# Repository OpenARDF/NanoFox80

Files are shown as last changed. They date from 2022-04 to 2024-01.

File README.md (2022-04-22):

# NanoFox80
NanoFox80 is a (relatively) simple full-featured low-power 80m transmitter for use in foxoring competitions.

<b>KiCad</b>

The KiCad folder holds files for generating the schematic, BOM, and PCB files using KiCad. 

<b>Software</b>

The Software folder holds files for compiling executable code on Atmel Studio 7.

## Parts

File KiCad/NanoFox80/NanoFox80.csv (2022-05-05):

Ref | Value | QTY PER | Footprint | Description | Digi-Key Part No. | LCSC Part Number | Link | Manufacturer | Manufacturer PN
AE101 | Antenna_Shield | 1 | Connector_PinHeader_2.54mm:PinHeader_1x02_P2.54mm_Vertical
BT101 | 6-12V | 1 | Connector_PinSocket_2.54mm:PinSocket_1x02_P2.54mm_Vertical
C101 C102 C106 C111 C112 C113 C116 C117 C122 C123 | 470nF | 10 | Capacitor_SMD:C_0805_2012Metric_Pad1.18x1.45mm_HandSolder |  | CAP CER 0.47UF 100V X7S 0805 | 445-5203-1-ND |  |  | TDK Corporation | C2012X7S2A474K125AB
C103 C104 C118 C119 | 10uF | 4 | Capacitor_SMD:C_0805_2012Metric_Pad1.18x1.45mm_HandSolder |  | CAP CER 10UF 10V X7R 0805 | 1276-1764-1-ND |  |  | Samsung Electro-Mechanics | CL21B106KPQNNNE
C105 | 220pF | 1 | Capacitor_SMD:C_0805_2012Metric_Pad1.18x1.45mm_HandSolder |  | CAP CER 220PF 200V C0G/NP0 0805 | 478-1274-1-ND |  |  | KYOCERA AVX | 08052A221JAT2A
C107 C120 | 10nF | 2 | Capacitor_SMD:C_0805_2012Metric_Pad1.18x1.45mm_HandSolder |  | CAP CER 10000PF 50V X7R 0805 | 1276-1015-1-ND |  |  | Samsung Electro-Mechanics | CL21B103KBANNNC
C108 C109 C121 | 100nF | 3 | Capacitor_SMD:C_0805_2012Metric_Pad1.18x1.45mm_HandSolder |  | CAP CER 0.1UF 25V X7R 0805 | 1276-1099-1-ND |  |  | Samsung Electro-Mechanics | CL21B104KACNNNC
C110 | 1uF | 1 | Capacitor_SMD:C_0805_2012Metric_Pad1.18x1.45mm_HandSolder |  | CAP CER 1UF 25V X7R 0805 | 1276-1066-1-ND |  |  | Samsung Electro-Mechanics | CL21B105KAFNNNE
C114 | 67pF | 1 | Capacitor_SMD:C_0805_2012Metric_Pad1.18x1.45mm_HandSolder |  | CAP CER 68PF 50V C0G/NP0 0805 | 478-1314-1-ND |  |  | KYOCERA AVX | 08055A680JAT2A
C115 | 560nF | 1 | Capacitor_SMD:C_0805_2012Metric_Pad1.18x1.45mm_HandSolder |  | CAP CER 0.56UF 50V X7R 0805 | 399-C0805C564K5RAC7800CT-ND |  |  | KEMET | C0805C564K5RAC7800
D101 | LED_Filled | 1 | LED_SMD:LED_APDA1806SECK |  | LED RED CLEAR SMD RIGHT ANGLE | 754-2329-1-ND |  |  | Kingbright | APDA1806SECK/J3-PRV
D102 | SMV1253-079LF | 1 | Diode_SMD:D_SC-80 |  | DIODE VAR HYPRABRUPT JUNC TUNING | 863-SMV1253-079LFCT-ND |  |  | Skyworks Solutions Inc. | SMV1253-079LF
FB101 | FerriteBead_Small | 1 | Inductor_SMD:Ferrite_Bead_NFZ32BW881_Reflow |  | FERRITE BEAD 880 OHM 2SMD 1LN | 490-9310-1-ND |  |  | Murata Electronics | NFZ32BW881HN10L
J101 J104 J105 J106 J107 J109 J112 J113 J114 J115 | Conn_01x02 | 10 | Connector_PinSocket_2.54mm:PinSocket_1x02_P2.54mm_Vertical
J102 | Conn_01x02 | 1 | Connector_PinSocket_2.54mm:PinSocket_1x02_P2.54mm_Vertical |  |  | np |  | np | np
J103 J108 | Conn_01x01 | 2 | Connector_PinSocket_2.54mm:PinSocket_1x01_P2.54mm_Vertical
J110 | I2C | 1 | Connector_PinHeader_2.54mm:PinHeader_1x02_P2.54_Nonpolarized
J111 | DB9 Female | 1 | Connector_Dsub:DSUB-9_Female_EdgeMount_P2.77mm |  |  | 609-1525-ND |  | <a href="https://www.digikey.com/products/en?keywords=609-1525-ND">Link</a> | TH | TH
JP101 JP102 JP103 JP104 JP105 | SolderJumper_3_Bridged12 | 5 | Jumper:SolderJumper-3_P1.3mm_Bridged12_RoundedPad1.0x1.5mm_NumberLabels
JP106 | SolderJumper_2_Bridged | 1 | Jumper:SolderJumper-2_P1.3mm_Bridged_RoundedPad1.0x1.5mm
L101 | 8uH | 1 | Transformer_THT:Autotransformer_Toroid_1Tap_Horizontal_D14.0mm_Amidon-T50 |  | FT-50-67 or FT-82-67 | FT-50-67 (Amidon) |  | <a href="http://www.amidoncorp.com/ft-50A-43/">Link</a> | TH | TH
P101 | ISP/PDI | 1 | Connector_PinHeader_2.54mm:PinHeader_2x03_P2.54mm_Vertical_SMD |  |  | 609-3487-1-ND |  | <a href="https://www.digikey.com/products/en?keywords=609-3487-1-ND">Link</a> | Amphenol ICC (FCI) | 95278-101A06LF
Q101 | BSS84W-7-F | 1 | Package_TO_SOT_SMD:SOT-323_SC-70 |  | MOSFET P-CH 50V 130MA SOT323 | BSS84W-FDICT-ND |  |  | Diodes Incorporated | BSS84W-7-F
Q102 | BSS138W-7-F | 1 | Package_TO_SOT_SMD:SOT-323_SC-70 |  | MOSFET N-CH 50V 200MA SOT323 | BSS138W-FDICT-ND |  |  | Diodes Incorporated | BSS138W-7-F
R101 R102 | 200k | 2 | Resistor_SMD:R_0805_2012Metric_Pad1.20x1.40mm_HandSolder |  | RES SMD 200K OHM 1% 1/8W 0805 | RHM200KAHCT-ND |  |  | Rohm Semiconductor | KTR10EZPF2003
R103 R107 | np | 2 | Resistor_SMD:R_0805_2012Metric_Pad1.20x1.40mm_HandSolder
R104 R109 R112 | 100k | 3 | Resistor_SMD:R_0805_2012Metric_Pad1.20x1.40mm_HandSolder |  | RES 100K OHM 0.1% 1/8W 0805 | 2019-RN73H2ATTD1003B25CT-ND |  |  | KOA Speer Electronics Inc. | RN73H2ATTD1003B25
R105 | 22k | 1 | Resistor_SMD:R_0805_2012Metric_Pad1.20x1.40mm_HandSolder |  | RES SMD 22K OHM 1% 1/8W 0805 | A106059CT-ND |  |  | TE Connectivity Passive Product | CRG0805F22K
R106 | 15.8k | 1 | Resistor_SMD:R_0805_2012Metric_Pad1.20x1.40mm_HandSolder |  | RES 15.8K OHM 1% 1/8W 0805 | RMCF0805FT15K8CT-ND |  |  | Stackpole Electronics Inc | RMCF0805FT15K8
R108 | 1k | 1 | Resistor_SMD:R_0805_2012Metric_Pad1.20x1.40mm_HandSolder |  | RES 1K OHM 1% 1/4W 0805 | RNCP0805FTD1K00CT-ND |  |  | Stackpole Electronics Inc | RNCP0805FTD1K00
R110 | 162k | 1 | Resistor_SMD:R_0805_2012Metric_Pad1.20x1.40mm_HandSolder |  | RES 162K OHM 1% 1/8W 0805 | 311-162KCRCT-ND |  |  | YAGEO | RC0805FR-07162KL
R111 | 12.4k | 1 | Resistor_SMD:R_0805_2012Metric_Pad1.20x1.40mm_HandSolder |  | RES 12.4K OHM 1% 1/8W 0805 | RMCF0805FT12K4CT-ND |  |  | Stackpole Electronics Inc | RMCF0805FT12K4
SW101 | SW_SPST | 1 | Button_Switch_SMD:SW_SPST_B3U-3000P-B |  | SWITCH TACTILE SPST-NO 0.05A 12V | SW1256CT-ND |  |  | Omron Electronics Inc-EMC Div | B3U-3000P-B
U101 | UCC27517DBVR | 1 | Package_TO_SOT_SMD:SOT-23-5 |  | IC GATE DRVR LOW-SIDE SOT23-5 | 296-39527-1-ND |  |  | Texas Instruments | UCC27517DBVR
U102 | LP2985-3.3 | 1 | Package_TO_SOT_SMD:SOT-23-5 |  | IC REG LINEAR 3.3V 150MA SOT23-5 | 296-18479-1-ND |  |  | Texas Instruments | LP2985A-33DBVR
U103 | LMV721M5 | 1 | Package_TO_SOT_SMD:SOT-23-5 |  | IC OPAMP GP 1 CIRCUIT SOT23-5 | LMV721M5/NOPBCT-ND |  | https://www.digikey.com/en/products/detail/texas-instruments/LMV721M5-NOPB/364402 | Texas Instruments | LMV721M5/NOPB
U104 | 74HC4046 | 1 | Package_SO:SOIC-16W_5.3x10.2mm_P1.27mm |  | IC PLL CMOS LOGIC W/VCO HS 16SO | SN74LV4046ANS-ND | C1535861 | https://www.digikey.com/products/en?keywords=SN74LV4046ANS-ND | Texas Instruments | SN74LV4046ANS
U105 | AVR128DA28 | 1 | Package_SO:SOIC-28W_7.5x17.9mm_P1.27mm |  | IC MCU 8BIT 128KB FLASH 28SOIC | 150-AVR128DA28T-E/SOCT-ND |  |  | Microchip Technology | AVR128DA28T-E/SO
U106 U107 | 74HC390 | 2 | Package_SO:SOIC-16W_5.3x10.2mm_P1.27mm |  | IC DUAL DECADE RIP CNTR 16SOIC | 296-33078-5-ND |  |  | Texas Instruments | CD74HC390M
U108 | LP2985-5.0 | 1 | Package_TO_SOT_SMD:SOT-23-5 |  | IC REG LINEAR 5V 150MA SOT23-5 | 296-20717-1-ND |  |  | Texas Instruments | LP2985-50DBVR
U109 | TXB0102DCU | 1 | Package_SO:VSSOP-8_2.4x2.1mm_P0.5mm |  | IC TRNSLTR BIDIRECTIONAL US8 | 296-32601-1-ND |  |  | Texas Instruments | TXB0102DCUT
W101 | TP2 | 1 | Measurement:Measurement_Point_ScopeProbe_Round-SMD-2sides-Pad_Small
W102 | TP3 | 1 | Measurement:Measurement_Point_ScopeProbe_Round-SMD-2sides-Pad_Small
W103 | TP1 | 1 | Measurement:Measurement_Point_ScopeProbe_Round-SMD-2sides-Pad_Small
X101 | SIT1566AC TCO | 1 | Oscillator:Oscillator_SMD_SiTime_SIT1566AC-4Pin_BGA |  | MEMS OSC TCXO 32.768KHZ CSP | 1473-SIT1566AC-JV-XXE-32.768ECT-ND |  |  | SiTime | SIT1566AC-JV-XXE-32.768E

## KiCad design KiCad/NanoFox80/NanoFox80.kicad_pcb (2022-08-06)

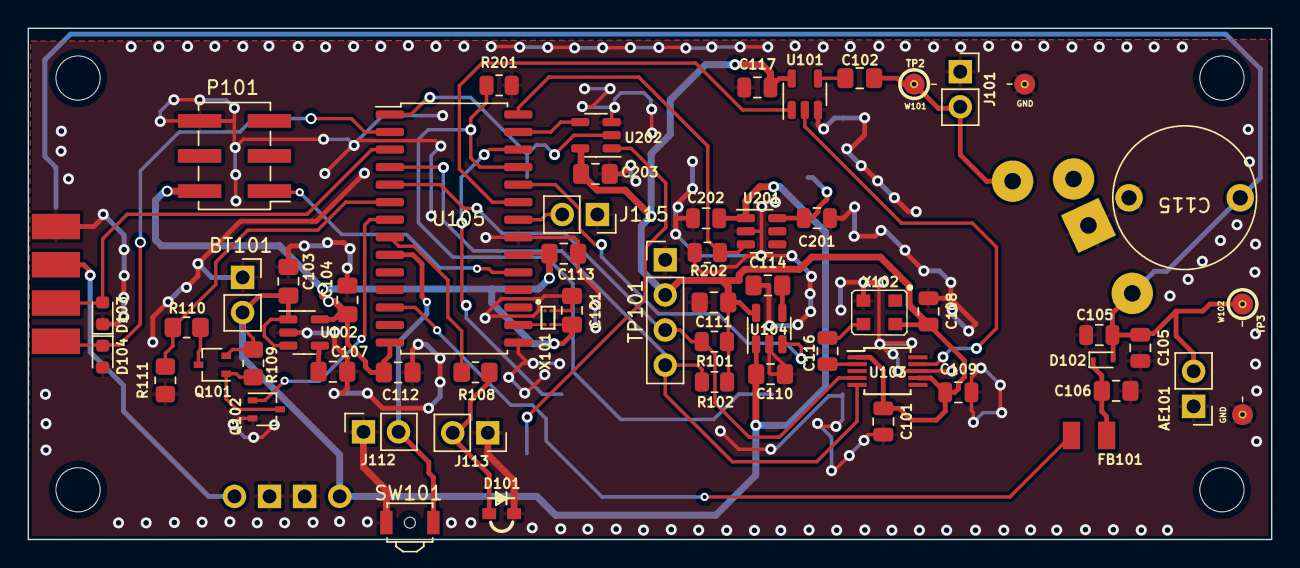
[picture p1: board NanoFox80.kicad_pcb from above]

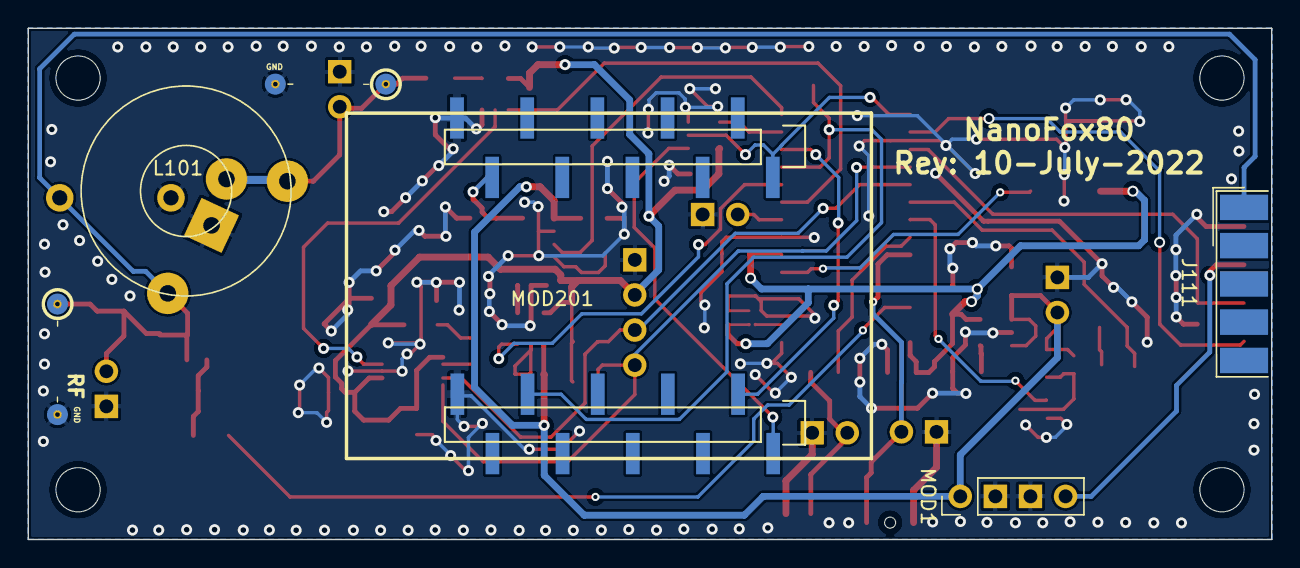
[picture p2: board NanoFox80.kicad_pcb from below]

Board: 2 copper layers, 90.0 x 37.0 mm, 61 parts (4 on the bottom side), 38 nets.

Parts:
AE101: Antenna_Shield; PinHeader_1x02_P2.54mm_Vertical
BT101: 3.5-9V; PinSocket_1x02_P2.54mm_Vertical
C101, C109: 470nF; C_0805_2012Metric
C102, C121, C203: 100nF; C_0805_2012Metric_Pad1.18x1.45mm_HandSolder
C103, C104, C110, C111: 10uF; C_0805_2012Metric_Pad1.18x1.45mm_HandSolder
C105, C105#2: 220pF; C_0805_2012Metric
C106, C112, C113: 470nF; C_0805_2012Metric_Pad1.18x1.45mm_HandSolder
C107, C114: 10nF; C_0805_2012Metric_Pad1.18x1.45mm_HandSolder
C108, C116, C117: 100nF; C_0805_2012Metric
C115: 15-60pF; CP_Radial_Ceramic_Trimmer_D9.4mm_P8.00mm
C201: 10uF; C_0805_2012Metric
C202: 4.7uF; C_0805_2012Metric
D101: LED_Filled; LED_APDA1806SECK
D102: SMV1253-079LF; D_SC-80
D103, D104: ESD9B5.0ST5G_1; D_0603_1608Metric
FB101: FerriteBead_Small; Ferrite_Bead_NFZ32BW881_Reflow
J101, J112, J113, J115: Conn_01x02; PinSocket_1x02_P2.54mm_Vertical
J111: DB9 Female; DSUB-9_Female_EdgeMount_P2.77mm
L101: 8uH; Autotransformer_Toroid_1Tap_Horizontal_D14.0mm_Amidon-T50
MOD1: AdaFruit Charger; PinHeader_1x04_P2.54mm_Vertical
MOD201: HUZZAH_ESP8266_Breakout; Adafruit_HUZZAH_ESP8266_Breakout_SM
P101: ISP/PDI; PinHeader_2x03_P2.54mm_Vertical_SMD
Q101: BSS84W-7-F; SOT-323_SC-70
Q102: BSS138W-7-F; SOT-323_SC-70
R101, R102, R202: 10k; R_0805_2012Metric
R108: 1k; R_0805_2012Metric_Pad1.20x1.40mm_HandSolder
R109: 100k; R_0805_2012Metric_Pad1.20x1.40mm_HandSolder
R110: 162k; R_0805_2012Metric_Pad1.20x1.40mm_HandSolder
R111: 12.4k; R_0805_2012Metric_Pad1.20x1.40mm_HandSolder
R201: 560k; R_0805_2012Metric
SW101: SW_SPST; SW_SPST_B3U-3000P-B
TP101: I2C1; PinHeader_1x04_P2.54mm_Vertical
U101: MC74VHC1G125; TSOT-23-5
U102, U104: LP2985-3.3; SOT-23-5
U103: SI5351; MSOP-10_3x3mm_P0.5mm
U105: AVR128DA28; SOIC-28W_7.5x17.9mm_P1.27mm
U201: TPS22810DBVT; SOT-23-6
U202: 74HC1G08; SOT-23-5
W101: TP2; Measurement_Point_ScopeProbe_Round-SMD-2sides-Pad_Small
W102: TP3; Measurement_Point_ScopeProbe_Round-SMD-2sides-Pad_Small
X101: SIT1566AC TCO; Oscillator_SMD_SiTime_SIT1566AC-4Pin_BGA
X102: 25 MHz; Crystal_SMD_TXETCLSANF-4Pin

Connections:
+3V3: C104.2, C112.1, C113.2, C121.2, P101.2, U102.5 (VOUT), U105.14 (AVDD), U105.20 (VDD), X101.3 (Vdd)
+BATT: BT101.2 (+), C103.2, C110.2, C202.2, MOD1.1, Q101.2 (S), R109.1, U102.1 (VIN), U102.3 (ON/~OFF), U104.1 (VIN), U201.1 (VIN)
Antenna: AE101.2 (A), C105.1, C105#2.1, C115.1, D102.2 (A), J111.1, L101.1, W102.1
Enable_RF: U104.3 (ON/~OFF), U105.24 (PA2)
Enable_Vdiv: Q102.1 (G), U105.7 (PD1)
GND: AE101.1 (Shield), BT101.1 (-), C101.2, C103.1, C104.1, C105.2, C105#2.2, C106.1, C107.2, C108.2, C109.2, C110.1, C111.1, C112.2, C113.1, C114.2, C115.2, C117.1, C121.1, C201.1, C202.1, C203.1, D101.1 (K), D103.1 (A1), D104.2 (A2), J101.1, J111.6, J112.1, J113.1, J115.1, L101.3, MOD1.2, MOD1.3, MOD201.10 (GND), MOD201.11 (GND), P101.6, Q102.2 (S), R111.1, R201.2, R202.1, SW101.2 (B), TP101.1, U101.3 (GND), U102.2 (GND), U103.8 (GND), U104.2 (GND), U105.15 (GND), U105.21 (GND), U201.2 (GND), U202.3 (GND), W101.2, W102.2, X101.4 (GND), X102.2 (GND)
unnamed: C102.1, J101.2, L101.2 (TAP), W101.1
unnamed: C102.2, U101.4 (Y)
unnamed: C106.2, D102.1 (K), FB101.1
unnamed: C107.1, U102.4 (BP)
unnamed: C114.1, U104.4 (BP)
unnamed: C116.1, U103.2 (XA)
unnamed: C116.2, X102.3 (OUT)
unnamed: C201.2, MOD201.9 (VBat), U201.6 (VOUT)
unnamed: D101.2 (A), J113.2, R108.2
unnamed: D103.2 (A2), J111.8, U105.3 (PC1/RxD1)
unnamed: D104.1 (A1), J111.9, U105.2 (PC0/TxD1)
unnamed: FB101.2, U105.12 (PD6/DAC)
unnamed: J112.2, SW101.1 (A), U105.9 (PD3)
unnamed: J115.2, U105.22 (PA0/EXTCLK)
unnamed: MOD201.20 (TX), U202.1
unnamed: P101.1, U105.19 (UDPI)
unnamed: Q101.1 (G), Q102.3 (D), R109.2
unnamed: Q101.3 (D), R110.2
unnamed: R101.2, TP101.3, U103.4 (SCL), U105.5 (PC3/SCL)
unnamed: R102.2, TP101.4, U103.5 (SDA), U105.4 (PC2/SDA)
unnamed: R108.1, U105.8 (PD2)
unnamed: U101.1 (~OE), U105.23 (PA1)
unnamed: U101.2 (A), U103.9 (CLK1)
unnamed: U105.16 (PF0/XTAL32k1), X101.2 (OUT)
V+_Charging: J111.7, MOD1.4
VCC: C101.1, C108.1, C109.1, C111.2, C117.2, C203.2, R101.1, R102.1, TP101.2, U101.5 (VCC), U103.1 (VDD), U103.7 (VDDO), U104.5 (VOUT), U202.5 (VCC), X102.4 (Vcc)
Vbat: R110.1, R111.2, U105.6 (PD0/AIN0)
WIFI_ENABLE: R202.2, U105.28 (PA6), U201.3 (EN/UVLO)
WIFI_RX: MOD201.19 (RX), U105.26 (PA4)
WIFI_TX: U105.27 (PA5), U202.4
WiFi Module Detect: MOD201.13 (3V), R201.1, U105.25 (PA3)
~WIFI_RESET: MOD201.1 (~RST), U105.1 (PA7), U202.2

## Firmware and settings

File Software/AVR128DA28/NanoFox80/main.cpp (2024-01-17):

#include "atmel_start.h"
#include <avr/io.h>
#include <avr/interrupt.h>
#include <string.h>
#include <time.h>
#include <stdio.h>
#include <ctype.h>
#include <avr/sleep.h>
#include <atomic.h>

#include "serialbus.h"
#include "transmitter.h"
#include "morse.h"
#include "adc.h"
#include "util.h"
#include "binio.h"
#include "eeprommanager.h"
#include "binio.h"
#include "leds.h"
#include "CircularStringBuff.h"
#include "rtc.h"
#include "rstctrl.h"

#include <cpuint.h>
#include <ccp.h>
#include <atomic.h>


/***********************************************************************
 * Local Typedefs
 ************************************************************************/

typedef enum
{
	WD_SW_RESETS,
	WD_HW_RESETS,
	WD_FORCE_RESET,
	WD_DISABLE
} WDReset;

typedef enum
{
	AWAKENED_INIT,
	POWER_UP_START,
	AWAKENED_BY_CLOCK,
	AWAKENED_BY_BUTTONPRESS
} Awakened_t;

typedef enum
{
	HARDWARE_OK,
	HARDWARE_NO_RTC = 0x01,
	HARDWARE_NO_SI5351 = 0x02
//	,HARDWARE_NO_WIFI = 0x04
} HardwareError_t;


typedef enum {
	SYNC_Searching_for_slave,
	SYNC_Align_to_Second_Transition,
	SYNC_Waiting_for_CLK_T_reply,
	SYNC_Waiting_for_CLK_S_reply,
	SYNC_Waiting_for_CLK_F_reply,
	SYNC_Waiting_for_CLK_D_reply,
	SYNC_Waiting_for_ID_reply,
	SYNC_Waiting_for_ID_CodeSpeed_reply,
	SYNC_Waiting_for_Pattern_CodeSpeed_reply,
	SYNC_Waiting_for_EVT_reply,
	SYNC_Waiting_for_NoEvent_Freq_reply,
	SYNC_Waiting_for_Freq_Low_reply,
	SYNC_Waiting_for_Freq_Med_reply,
	SYNC_Waiting_for_Freq_Hi_reply,
	SYNC_Waiting_for_Freq_Beacon_reply,
// 	SYNC_Waiting_for_PAT_A_reply,
// 	SYNC_Waiting_for_PAT_B_reply,
// 	SYNC_Waiting_for_PAT_C_reply,
// 	SYNC_Waiting_for_FRE_A_reply,
// 	SYNC_Waiting_for_FRE_B_reply,
// 	SYNC_Waiting_for_FRE_C_reply,
	SYNC_Waiting_for_ACK
} SyncState_t;

#define PROGRAMMING_MESSAGE_TIMEOUT_PERIOD 9000


/***********************************************************************
 * Global Variables & String Constants
 *
 * Identify each global with a "g_" prefix
 * Whenever possible limit globals' scope to this file using "static"
 * Use "volatile" for globals shared between ISRs and foreground
 ************************************************************************/
#define TEMP_STRING_SIZE 50
static char g_tempStr[TEMP_STRING_SIZE+1] = { '\0' };
static volatile EC g_last_error_code = ERROR_CODE_NO_ERROR;
static volatile SC g_last_status_code = STATUS_CODE_IDLE;

static volatile bool g_powering_off = false;

static volatile uint16_t g_util_tick_countdown = 0;
static volatile bool g_battery_measurements_active = false;
static volatile uint16_t g_maximum_battery = 0;

static volatile bool g_start_event = false;

static volatile int32_t g_on_the_air = 0;
static volatile int g_sendID_seconds_countdown = 0;
static volatile uint16_t g_code_throttle = 50;
static volatile uint16_t g_sleepshutdown_seconds = 120;
static volatile bool g_report_seconds = false;
static volatile int g_hardware_error = (int)HARDWARE_OK;

char g_messages_text[STATION_ID+1][MAX_PATTERN_TEXT_LENGTH + 2];
volatile uint8_t g_id_codespeed = EEPROM_ID_CODE_SPEED_DEFAULT;
volatile uint8_t g_pattern_codespeed = EEPROM_PATTERN_CODE_SPEED_DEFAULT;
volatile uint8_t g_foxoring_pattern_codespeed = EEPROM_FOXORING_PATTERN_CODESPEED_DEFAULT;
volatile uint16_t g_time_needed_for_ID = 0;
volatile int16_t g_on_air_seconds = EEPROM_ON_AIR_TIME_DEFAULT;                      /* amount of time to spend on the air */
volatile int16_t g_off_air_seconds = EEPROM_OFF_AIR_TIME_DEFAULT;                    /* amount of time to wait before returning to the air */
volatile int16_t g_intra_cycle_delay_time = EEPROM_INTRA_CYCLE_DELAY_TIME_DEFAULT;   /* offset time into a repeating transmit cycle */
volatile int16_t g_ID_period_seconds = EEPROM_ID_TIME_INTERVAL_DEFAULT;              /* amount of time between ID/callsign transmissions */
volatile time_t g_event_start_epoch = EEPROM_START_TIME_DEFAULT;
volatile time_t g_event_finish_epoch = EEPROM_FINISH_TIME_DEFAULT;
volatile bool g_event_enabled = EEPROM_EVENT_ENABLED_DEFAULT;                        /* indicates that the conditions for executing the event are set */
volatile bool g_event_commenced = false;
volatile float g_voltage_threshold = EEPROM_BATTERY_THRESHOLD_V;
volatile float g_battery_voltage = 0.;
volatile bool g_seconds_transition = false;
volatile bool g_sending_station_ID = false;											/* Allows a small extension of transmissions to ensure the ID is fully sent */
volatile bool g_muteAfterID = false;												/* Inhibit any transmissions after the ID has been sent */
volatile uint32_t g_event_checksum = 0;
volatile uint8_t g_days_to_run = 1;
volatile uint8_t g_days_run = 0;
extern uint16_t g_clock_calibration;

static volatile bool g_run_event_forever = false;
static volatile bool g_go_to_sleep_now = false;
static volatile bool g_sleeping = false;
static volatile time_t g_time_to_wake_up = 0;
static volatile Awakened_t g_awakenedBy = POWER_UP_START;
static volatile SleepType g_sleepType = SLEEP_FOREVER;

#define NUMBER_OF_POLLED_ADC_CHANNELS 1
static ADC_Active_Channel_t g_adcChannelOrder[NUMBER_OF_POLLED_ADC_CHANNELS] = { ADCExternalBatteryVoltage };
enum ADC_Result_Order { EXTERNAL_BATTERY_VOLTAGE };
static const uint16_t g_adcChannelConversionPeriod_ticks[NUMBER_OF_POLLED_ADC_CHANNELS] = { TIMER2_0_5HZ };
static volatile uint16_t g_adcCountdownCount[NUMBER_OF_POLLED_ADC_CHANNELS] = { 2000 };
//static uint16_t g_ADCFilterThreshold[NUMBER_OF_POLLED_ADC_CHANNELS] = { 500, 500, 500 };
static volatile bool g_adcUpdated[NUMBER_OF_POLLED_ADC_CHANNELS] = { false };
static volatile uint16_t g_lastConversionResult[NUMBER_OF_POLLED_ADC_CHANNELS];

volatile uint16_t g_switch_closed_time = 0;
volatile uint16_t g_handle_counted_presses = 0;
volatile uint16_t g_switch_presses_count = 0;
volatile bool g_long_button_press = false;

static volatile uint16_t g_programming_countdown = 0;
static volatile uint16_t g_programming_msg_throttle = 0;
static volatile uint16_t g_send_clone_success_countdown = 0;
static SyncState_t g_programming_state = SYNC_Searching_for_slave;
bool g_cloningInProgress = false;
Enunciation_t g_enunciator = LED_ONLY;

uint16_t g_Event_Configuration_Check = 0;

leds LEDS = leds();
CircularStringBuff g_text_buff = CircularStringBuff(TEXT_BUFF_SIZE);

EepromManager g_ee_mgr;

bool g_isMaster = false;
uint16_t isMasterCountdownSeconds = 0;
Fox_t g_fox[] = {FOX_1, FOX_1, SPRINT_S1, FOXORING_FOX1, INVALID_FOX}; /* none, classic, sprint, foxoring, blind */

Event_t g_event = EEPROM_EVENT_SETTING_DEFAULT;
Frequency_Hz g_frequency = EEPROM_FREQUENCY_DEFAULT;
Frequency_Hz g_frequency_low = EEPROM_FREQUENCY_LOW_DEFAULT;
Frequency_Hz g_frequency_med = EEPROM_FREQUENCY_MED_DEFAULT;
Frequency_Hz g_frequency_hi = EEPROM_FREQUENCY_HI_DEFAULT;
Frequency_Hz g_frequency_beacon = EEPROM_FREQUENCY_BEACON_DEFAULT;

int8_t g_utc_offset;
uint8_t g_unlockCode[UNLOCK_CODE_SIZE + 2];

extern volatile uint16_t g_i2c_failure_count;

volatile bool g_enable_manual_transmissions = true;

/***********************************************************************
 * Private Function Prototypes
 *
 * These functions are available only within this file
 ************************************************************************/
void handle_1sec_tasks(void);
bool eventEnabled(void);
void handleSerialBusMsgs(void);
void wdt_init(WDReset resetType);
uint16_t throttleValue(uint8_t speed);
EC activateEventUsingCurrentSettings(SC* statusCode);
EC launchEvent(SC* statusCode);
EC hw_init(void);
EC rtc_init(void);
bool antennaIsConnected(void);
void powerDown3V3(void);
void powerUp3V3(void);
char* convertEpochToTimeString(time_t epoch, char* buf, size_t size);
time_t String2Epoch(bool *error, char *datetime);
void reportSettings(void);
uint16_t timeNeededForID(void);
Frequency_Hz getFrequencySetting(void);
char* getCurrentPatternText(void);
int getPatternCodeSpeed(void);
int getFoxCodeSpeed(void);
Fox_t getFoxSetting(void);
void handleSerialCloning(void);
bool eventScheduled(void);
bool eventScheduledForNow(void);
bool eventScheduledForTheFuture(void);
bool noEventWillRun(void);
time_t pauseUntilSecTransition(void);

/*******************************/
/* Hardcoded event support     */
/*******************************/
void initializeAllEventSettings(bool disableEvent);
void suspendEvent(void);
void stopEventNow(EventActionSource_t activationSource);
void startEventNow(EventActionSource_t activationSource);
bool startEventUsingRTC(void);
void setupForFox(Fox_t fox, EventAction_t action);
time_t validateTimeString(char* str, time_t* epochVar);
bool reportTimeTill(time_t from, time_t until, const char* prefix, const char* failMsg);
ConfigurationState_t clockConfigurationCheck(void);
void reportConfigErrors(void);
/*******************************/
/* End hardcoded event support */
/*******************************/

ISR(RTC_CNT_vect)
{
	uint8_t x = RTC.INTFLAGS;
	
    if (x & RTC_OVF_bm )
    {
        system_tick();

		if(g_on_the_air < 0)
		{
			g_on_the_air++;
		}
		else if(g_on_the_air > 0)
		{
			g_on_the_air--;
		}
		
		g_seconds_transition = true;

		if(g_sleeping)
		{
			if(g_sleepType != SLEEP_FOREVER)
			{
				if(g_sleepType == SLEEP_UNTIL_NEXT_XMSN)
				{
					if((g_on_the_air > -6) || (g_time_to_wake_up <= time(null))) /* Always wake up at least 5 seconds before showtime */
					{
						g_go_to_sleep_now = false;
						g_sleeping = false;
						g_awakenedBy = AWAKENED_BY_CLOCK;
					}
				}
				else
				{
					if(g_time_to_wake_up <= time(null))
					{
						g_go_to_sleep_now = false;
						g_sleeping = false;
						g_awakenedBy = AWAKENED_BY_CLOCK;
					}
				}
			}
		}
		else
		{
			handle_1sec_tasks();
		}
	}
 
    RTC.INTFLAGS = (RTC_OVF_bm | RTC_CMP_bm);
}


/**
1-Second Interrupts:
One-second counter based on RTC.
*/
void handle_1sec_tasks(void)
{
	time_t temp_time = 0;
	
	if(isMasterCountdownSeconds) isMasterCountdownSeconds--;

	if(!g_cloningInProgress)
	{
		temp_time = time(null);

		if(g_event_commenced && !g_run_event_forever)
		{
			if(g_event_finish_epoch) /* If a finish time has been set */
			{
				if(temp_time >= g_event_finish_epoch)
				{
					g_last_status_code = STATUS_CODE_EVENT_FINISHED;
					g_on_the_air = 0;
					keyTransmitter(OFF);
					g_event_enabled = false;
					g_event_commenced = false;
					g_sleepshutdown_seconds = 120;
					LEDS.init();
					g_days_run++;
				
					if(g_days_run < g_days_to_run)
					{
						g_event_start_epoch += SECONDS_24H;
						g_event_finish_epoch += SECONDS_24H;
						g_sleepType = SLEEP_UNTIL_START_TIME;
						g_go_to_sleep_now = true;
					}
					else
					{
						g_sleepType = SLEEP_FOREVER;
						g_sleepshutdown_seconds = 3;
					}
				}
			}
		}

		if(g_event_enabled && !g_isMaster)
		{
			if(g_event_commenced) /* an event is in progress */
			{
				if(g_sendID_seconds_countdown)
				{
					g_sendID_seconds_countdown--;
				}
				
 				if(g_fox[g_event] == FREQUENCY_TEST_BEACON)
 				{
					static uint8_t selection = 0;
 					bool change = temp_time % 2;
 					
					if(!change)
					{
						if(selection == 0)
						{
							init_transmitter(g_frequency_low);
							g_code_throttle = throttleValue(14);
							bool repeat = true;
							makeMorse((char*)"E<<", &repeat, NULL, CALLER_AUTOMATED_EVENT);
							selection = 1;
						}
						else if(selection == 1)
						{
							init_transmitter(g_frequency_med);
							g_code_throttle = throttleValue(14);
							bool repeat = true;
							makeMorse((char*)"I<<", &repeat, NULL, CALLER_AUTOMATED_EVENT);
							selection = 2;
						}
						else if(selection == 2)
						{
							init_transmitter(g_frequency_hi);
							g_code_throttle = throttleValue(14);
							bool repeat = true;
							makeMorse((char*)"S<<", &repeat, NULL, CALLER_AUTOMATED_EVENT);
							selection = 0;
						}
					}
 				}
			}
			else /* waiting for the start time to arrive */
			{
				if(g_event_start_epoch > MINIMUM_VALID_EPOCH) /* a start time has been set */
				{
					temp_time = time(null);

					if(temp_time >= g_event_start_epoch) /* Time for the event to start */
					{
						powerToTransmitter(ON);
				
						if(g_intra_cycle_delay_time)
						{
							g_last_status_code = STATUS_CODE_EVENT_STARTED_WAITING_FOR_TIME_SLOT;
							g_on_the_air = -g_intra_cycle_delay_time;
							g_sendID_seconds_countdown = g_intra_cycle_delay_time + g_on_air_seconds - g_time_needed_for_ID;
						}
						else
						{
							g_last_status_code = STATUS_CODE_EVENT_STARTED_NOW_TRANSMITTING;
							g_on_the_air = g_on_air_seconds;
							g_sendID_seconds_countdown = g_on_air_seconds - g_time_needed_for_ID;
						}
						
						g_code_throttle = throttleValue(getFoxCodeSpeed());
						bool repeat = true;
						makeMorse(getCurrentPatternText(), &repeat, NULL, CALLER_AUTOMATED_EVENT);
						
						g_event_commenced = true;
						LEDS.init();
					}
				}
			}
		}
	}

	/**************************************
	* Delay before sleep
	***************************************/
	if(g_sleepshutdown_seconds) g_sleepshutdown_seconds--;

	if(!g_sleepshutdown_seconds)
	{
 		if(g_isMaster || g_cloningInProgress)
 		{
	 		g_sleepshutdown_seconds = 120; /* Never sleep while cloning or while master */
 		}
		else if(g_event_commenced && g_event_enabled && ((g_sleepType != SLEEP_UNTIL_NEXT_XMSN) && (g_sleepType != SLEEP_UNTIL_START_TIME)))
		{
			g_sleepshutdown_seconds = 120; /* Never sleep during active transmissions */
		}
		else
		{
			if(g_sleepType == DO_NOT_SLEEP)
			{
				if(noEventWillRun()) /* Should never evaluate to true, but checking just in case */
				{
					g_sleepType = SLEEP_FOREVER;
				}
			}
			else if(!g_go_to_sleep_now)
			{
				if(g_sleepType == SLEEP_FOREVER)
				{
					if(eventScheduledForTheFuture()) /* Should never evaluate to true, but checking just in case */
					{
						g_sleepType = SLEEP_UNTIL_START_TIME;
					}
				}
				
				/* If we reach here, g_sleepType = 	SLEEP_UNTIL_START_TIME, SLEEP_UNTIL_NEXT_XMSN, SLEEP_USER_OVERRIDE, or SLEEP_FOREVER */
				g_go_to_sleep_now = true;
			}
		}
	}
}
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
int main(void)
{
	atmel_start_init();
	LEDS.blink(LEDS_OFF, true);
	powerUp3V3();
	
	g_ee_mgr.initializeEEPROMVars();
	g_ee_mgr.readNonVols();
	g_isMaster = false; /* Never start up as master */
	
	RTC_set_calibration(g_clock_calibration);
					
	/* Check that the RTC is running */
	set_system_time(YEAR_2000_EPOCH);
	time_t now = time(null);
	while((util_delay_ms(2000)) && (now == time(null)));
	
	sb_send_string(TEXT_RESET_OCCURRED_TXT);
	
	if(now == time(null))
	{
		g_hardware_error |= (int)HARDWARE_NO_RTC;
		RTC_init_backup();
	}
	
	if(init_transmitter(getFrequencySetting()) != ERROR_CODE_NO_ERROR)
	{
		if(!txIsInitialized())
		{
			g_hardware_error |= (int)HARDWARE_NO_SI5351;
		}
	}
	
	g_start_event = eventEnabled(); /* Start any event stored in EEPROM */
	
	reportSettings();
	sb_send_NewPrompt();

	g_sleepshutdown_seconds = 120;

	while (1) {
		if(g_handle_counted_presses)
		{
			if(g_handle_counted_presses == 1)
			{
				if(!g_isMaster && !g_cloningInProgress)
				{
					if(eventScheduled())
					{
						g_event_enabled = false;
						
						if(!g_run_event_forever)
						{
							setupForFox(INVALID_FOX, START_EVENT_NOW_AND_RUN_FOREVER); // Immediately start transmissions
						}
						else
						{
 							startEventUsingRTC();
						}
					}
					else
					{
						startEventNow(PROGRAMMATIC);						
					}
				}
			}
			else if (g_handle_counted_presses == 2)
			{
				suspendEvent();
				g_sleepType = SLEEP_USER_OVERRIDE;
			}
			else if(g_isMaster)
			{
				if((g_handle_counted_presses == 4) && txIsInitialized()) // keydown forever
				{
					suspendEvent();
					g_sleepType = SLEEP_USER_OVERRIDE;
					keyTransmitter(ON);
					LEDS.setRed(ON);
					g_sleepshutdown_seconds = 300; // Shut things down after 5 minutes
				}
				else if (g_handle_counted_presses == 5) // Perform software reset
				{
					RSTCTRL_reset();
				}
			}
			
			g_handle_counted_presses = 0;
		}
		
		if(g_isMaster)
		{
			handleSerialCloning();
			
			if(g_text_buff.empty())
			{
				if(g_send_clone_success_countdown)
				{
					LEDS.sendCode((char*)"X ");
				}
				else
				{
					LEDS.sendCode((char*)"M ");
				}
			}
			else /* Make sure the text buffer is being emptied */
			{
				g_enable_manual_transmissions = true; /* There is only one consumer of g_text_buff so it is always OK to enable manual transmissions */
			}
			
			if(!isMasterCountdownSeconds)
			{
				g_isMaster = false;
				g_sleepshutdown_seconds = 240; /* Ensure sleep occurs */
				g_send_clone_success_countdown = 0;
				g_start_event = eventEnabled(); /* Start any event stored in EEPROM */
				LEDS.init();
			}
		}
		else
		{
			handleSerialBusMsgs();
			
			if(g_cloningInProgress && !g_programming_countdown)
			{
				g_cloningInProgress = false;
			}

			if(g_text_buff.empty())
			{
				if((g_battery_voltage >= 0.1) && (g_battery_voltage <= g_voltage_threshold))
				{
					LEDS.sendCode((char*)"V ");
				}
				else if(g_cloningInProgress)
				{
					LEDS.blink(LEDS_RED_ON_CONSTANT, true);
				}
				else if(g_hardware_error & ((int)HARDWARE_NO_RTC | (int)HARDWARE_NO_SI5351 ))
				{
					LEDS.blink(LEDS_RED_BLINK_FAST);
				}
				else if(!g_event_commenced)
				{
					if(g_send_clone_success_countdown)
					{
						LEDS.sendCode((char*)"X ");
					}
					else
					{
						if(noEventWillRun()) /* No event is running now, nor will one run in the future */
						{
							LEDS.blink(LEDS_RED_BLINK_FAST);
						}
						else if(eventScheduled()) /* An event is scheduled to run in the future = OK */
						{
							LEDS.sendCode((char*)"E  ");
						}
						else /* Should not reach here, but if we do, it is an error */
						{
							LEDS.blink(LEDS_RED_BLINK_FAST);
						}
					}
				}	
			}
			else /* Make sure the text buffer is being emptied */
			{
				g_enable_manual_transmissions = true; /* There is only one consumer of g_text_buff so it is always OK to enable manual transmissions */
			}
		}
		
		if(g_long_button_press)
		{
			g_long_button_press = false;
			g_isMaster = !g_isMaster;
			
			if(g_isMaster)
			{
				g_event_commenced = false;
				isMasterCountdownSeconds = 600; /* Remain Master for 10 minutes */
				g_sleepshutdown_seconds = 720;
			}
			else
			{
				isMasterCountdownSeconds = 0;
				g_sleepshutdown_seconds = 120;
				sb_send_NewPrompt();
				g_event_commenced = false;
				g_start_event = true;
			}
			
			g_cloningInProgress = false;
			g_programming_countdown = 0;
			g_send_clone_success_countdown = 0;
			LEDS.init();
			g_text_buff.reset();
		}
		
		if(g_start_event)
		{
			g_start_event = false;
			
			if(!g_isMaster)
			{
				g_last_error_code = launchEvent((SC*)&g_last_status_code);
				g_sleepshutdown_seconds = 120;
			}
		}
				
		/********************************
		 * Handle sleep
		 ******************************/
		if(g_go_to_sleep_now && !g_cloningInProgress)
		{
			DISABLE_INTERRUPTS();
			LEDS.deactivate();
			serialbus_disable();
			shutdown_transmitter();	

			if((g_sleepType == SLEEP_FOREVER) || (g_sleepType == SLEEP_USER_OVERRIDE))
			{
				g_time_to_wake_up = FOREVER_EPOCH;
			}
			
			system_sleep_config();

			SLPCTRL_set_sleep_mode(SLPCTRL_SMODE_STDBY_gc);		
			g_sleeping = true;
			g_awakenedBy = AWAKENED_INIT;
			ENABLE_INTERRUPTS();
			
			/* Disable BOD? */
			
 			while(g_go_to_sleep_now)
 			{
				set_sleep_mode(SLEEP_MODE_STANDBY);
//					set_sleep_mode(SLEEP_MODE_PWR_DOWN);
				DISABLE_INTERRUPTS();
				sleep_enable();
				ENABLE_INTERRUPTS();
				sleep_cpu();  /* Sleep occurs here */
				sleep_disable();
 			}
 
			CLKCTRL_init();
			/* Re-enable BOD? */
			g_sleeping = false;
			atmel_start_init();
			
			if(g_awakenedBy != AWAKENED_BY_BUTTONPRESS)
			{	
				serialbus_disable();
			}

			powerUp3V3();
			RTC_set_calibration(g_clock_calibration);
			while(util_delay_ms(2000));
			init_transmitter();
			g_sleepshutdown_seconds = 120;
			
			if(g_awakenedBy == AWAKENED_BY_BUTTONPRESS)
			{
				LEDS.blink(LEDS_OFF, true); /* Restart LED timeout */
			}
			else
			{
				if(g_sleepType != SLEEP_UNTIL_NEXT_XMSN)
				{
					g_start_event = true;
				}
			}

 			g_last_status_code = STATUS_CODE_RETURNED_FROM_SLEEP;
		}
		
		if(g_i2c_failure_count)
		{
			static time_t t = 0;
			time_t now = time(null);
			
			if(difftime(now, t) > 600) /* Update no more often than every 10 minutes */
			{
				t = now;
				g_ee_mgr.updateEEPROMVar(I2C_failure_count, (void*)&g_i2c_failure_count);
			}
		}
	}
}
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

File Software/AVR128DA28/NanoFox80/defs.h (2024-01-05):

/**********************************************************************************************
* Copyright © 2017 Digital Confections LLC
*
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
**********************************************************************************************/

#ifndef DEFS_H
#define DEFS_H

#ifndef F_CPU
 #define F_CPU 24000000UL /* gets declared in makefile */
#endif

#include <avr/io.h>
#include <avr/interrupt.h>

/******************************************************
 * Set the text that gets displayed to the user */
#define SW_REVISION "0.99"

//#define TRANQUILIZE_WATCHDOG

#define PRODUCT_NAME_SHORT "NanoFox ARDF Tx"
#define PRODUCT_NAME_LONG "\n* NanoFox 80m ARDF Transmitter"

/*******************************************************/

/******************************************************
 * Include only the necessary hardware and software support */
#define INCLUDE_SI5351_SUPPORT true // Silicon Labs Programmable Clock
#define DATE_STRING_SUPPORT_ENABLED

/*******************************************************/
/* Error Codes                                                                   */
/*******************************************************/
typedef enum {
	ERROR_CODE_NO_ERROR = 0x00,
	ERROR_CODE_REPORT_NO_ERROR = 0x01,
	ERROR_CODE_EVENT_STATION_ID_ERROR = 0xC7,
	ERROR_CODE_EVENT_PATTERN_CODE_SPEED_NOT_SPECIFIED = 0xC8,
	ERROR_CODE_EVENT_PATTERN_NOT_SPECIFIED = 0xC9,
	ERROR_CODE_EVENT_TIMING_ERROR = 0xCA,
	ERROR_CODE_EVENT_MISSING_TRANSMIT_DURATION = 0xCB,
	ERROR_CODE_EVENT_MISSING_START_TIME = 0xCC,
	ERROR_CODE_EVENT_NOT_CONFIGURED = 0xCD,
    ERROR_CODE_ILLEGAL_COMMAND_RCVD = 0xCE,
    ERROR_CODE_SW_LOGIC_ERROR = 0xCF,
	ERROR_CODE_EVENT_ENDED_IN_PAST = 0xD0,
	ERROR_CODE_ATMEGA_NOT_RESPONDING = 0xD1,
	ERROR_CODE_RF_OSCILLATOR_ERROR = 0xD2,
	ERROR_CODE_POWER_LEVEL_NOT_SUPPORTED = 0xF5,
	ERROR_CODE_NO_ANTENNA_PREVENTS_POWER_SETTING = 0xF6,
	ERROR_CODE_NO_ANTENNA_FOR_BAND = 0xF7,
	ERROR_CODE_WD_TIMEOUT = 0xF8,
	ERROR_CODE_SUPPLY_VOLTAGE_ERROR = 0xF9,
	ERROR_CODE_BUCK_REG_OUTOFSPEC = 0xFA,
	ERROR_CODE_CLKGEN_NONRESPONSIVE = 0xFB,
	ERROR_CODE_RTC_NONRESPONSIVE = 0xFC,
	ERROR_CODE_DAC3_NONRESPONSIVE = 0xFD,
	ERROR_CODE_DAC2_NONRESPONSIVE = 0xFE,
	ERROR_CODE_DAC1_NONRESPONSIVE = 0xFF
	} EC;

/*******************************************************/
/* Status Codes                                                                 */
/*******************************************************/
typedef enum {
	STATUS_CODE_IDLE = 0x00,
	STATUS_CODE_REPORT_IDLE = 0x01,
	STATUS_CODE_NO_ANT_ATTACHED = 0xE9,
//	STATUS_CODE_2M_ANT_ATTACHED = 0xEA,
	STATUS_CODE_80M_ANT_ATTACHED = 0xEB,
	STATUS_CODE_RECEIVING_EVENT_DATA = 0xEC,
	STATUS_CODE_RETURNED_FROM_SLEEP = 0xED,
	STATUS_CODE_BEGINNING_XMSN_THIS_CYCLE = 0xEE,
	STATUS_CODE_SENDING_ID = 0xEF,
	STATUS_CODE_NO_EVENT_TO_RUN = 0xFA,
	STATUS_CODE_EVENT_NEVER_ENDS = 0xFB,
	STATUS_CODE_EVENT_FINISHED = 0xFC,
	STATUS_CODE_EVENT_STARTED_NOW_TRANSMITTING = 0xFD,
	STATUS_CODE_EVENT_STARTED_WAITING_FOR_TIME_SLOT = 0xFE,
	STATUS_CODE_WAITING_FOR_EVENT_START = 0xFF
	} SC;

typedef enum {
	DO_NOT_SLEEP,
	SLEEP_UNTIL_START_TIME,
	SLEEP_AFTER_EVENT,
	SLEEP_UNTIL_NEXT_XMSN,
	SLEEP_USER_OVERRIDE,
	SLEEP_FOREVER
	} SleepType;
	

typedef enum {
	DO_NOT_ENUNCIATE,
	LED_AND_RF,
	LED_ONLY
	} Enunciation_t;
	
#define ENUNCIATION_BLINK_WPM 8

/*******************************************************/

#ifndef uint16_t_defined
#define uint16_t_defined
typedef unsigned int uint16_t;
#endif

#ifndef uint32_t_defined
#define uint32_t_defined
typedef unsigned long uint32_t;
#endif

#ifndef unit8_t_defined
#define unit8_t_defined
typedef unsigned char uint8_t;
#endif

#ifndef null
#define null 0
#endif

#ifndef PI
#define PI 3.141592653589793
#endif

#ifndef MINUTE
#define MINUTE 60UL
#endif

#ifndef HOUR
#define HOUR 3600UL
#endif

#ifndef DAY
#define DAY 86400UL
#endif

#ifndef YEAR
#define YEAR 31536000UL
#endif

#ifndef UINT16_MAX
#define UINT16_MAX 0xFFFFU
#endif

/*******************************************************/
/*******************************************************
* ADC Scale Factors */
/* Battery voltage should be read when +12V supply is enabled and all transmitters are fully powered off */
#define ADC_REF_VOLTAGE_mV 1100UL

#define ADC_MAX_VOLTAGE_MV 4200L /* maximum voltage the ADC can read */
#define BATTERY_VOLTAGE_MAX_MV 4200L /* voltage at which the battery is considered to be fully charged */
#define BATTERY_DROP 320L /* voltage drop between the battery terminals and the ADC input while powering the ESP8266 */
#define BATTERY_DROP_OFFSET (BATTERY_DROP * 1023L)
#define VBAT(x) (BATTERY_DROP + (x * ADC_MAX_VOLTAGE_MV) / 1023L)
#define BATTERY_PERCENTAGE(x, y) ( ( 100L * ((x * ADC_MAX_VOLTAGE_MV + BATTERY_DROP_OFFSET) - (1023L * y)) )  / ((BATTERY_VOLTAGE_MAX_MV - y) * 1023L))

#define SUPPLY_VOLTAGE_MAX_MV 14100L
#define VSUPPLY(x)((x * SUPPLY_VOLTAGE_MAX_MV) / 1023L)

#define PA_VOLTAGE_MAX_MV 14100L
#define VPA(x)((x * PA_VOLTAGE_MAX_MV) / 1023L)
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

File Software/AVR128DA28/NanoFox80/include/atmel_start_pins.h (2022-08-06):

/*
 * Code generated from START.
 *
 * This file will be overwritten when reconfiguring your START project.
 * Please copy examples or other code you want to keep to a separate file
 * to avoid losing it when reconfiguring.
 */
#ifndef ATMEL_START_PINS_H_INCLUDED
#define ATMEL_START_PINS_H_INCLUDED

#include <port.h>

/************************************************************************************
PORTA Helper Functions
*************************************************************************************/

/**
 * \brief Set PA0 pull mode
 *
 * Configure pin to pull up, down or disable pull mode, supported pull
 * modes are defined by device used
 *
 * \param[in] pull_mode Pin pull mode
 */
static inline void PA0_set_pull_mode(const enum port_pull_mode pull_mode)
{
	PORTA_set_pin_pull_mode(0, pull_mode);
}

/**
 * \brief Set PA0 data direction
 *
 * Select if the pin data direction is input, output or disabled.
 * If disabled state is not possible, this function throws an assert.
 *
 * \param[in] direction PORT_DIR_IN  = Data direction in
 *                      PORT_DIR_OUT = Data direction out
 *                      PORT_DIR_OFF = Disables the pin
 *                      (low power state)
 */
static inline void PA0_set_dir(const enum port_dir dir)
{
	PORTA_set_pin_dir(0, dir);
}

/**
 * \brief Set PA0 input/sense configuration
 *
 * Enable/disable PA0 digital input buffer and pin change interrupt,
 * select pin interrupt edge/level sensing mode
 *
 * \param[in] isc PORT_ISC_INTDISABLE_gc    = Iterrupt disabled but input buffer enabled
 *                PORT_ISC_BOTHEDGES_gc     = Sense Both Edges
 *                PORT_ISC_RISING_gc        = Sense Rising Edge
 *                PORT_ISC_FALLING_gc       = Sense Falling Edge
 *                PORT_ISC_INPUT_DISABLE_gc = Digital Input Buffer disabled
 *                PORT_ISC_LEVEL_gc         = Sense low Level
 */
static inline void PA0_set_isc(const PORT_ISC_t isc)
{
	PORTA_pin_set_isc(0, isc);
}

/**
 * \brief Set PA0 inverted mode
 *
 * Enable or disable inverted I/O on a pin
 *
 * \param[in] inverted true  = I/O on PA0 is inverted
 *                     false = I/O on PA0 is not inverted
 */
static inline void PA0_set_inverted(const bool inverted)
{
	PORTA_pin_set_inverted(0, inverted);
}

/**
 * \brief Set PA0 level
 *
 * Sets output level on a pin
 *
 * \param[in] level true  = Pin level set to "high" state
 *                  false = Pin level set to "low" state
 */
static inline void PA0_set_level(const bool level)
{
	PORTA_set_pin_level(0, level);
}

/**
 * \brief Toggle output level on PA0
 *
 * Toggle the pin level
 */
static inline void PA0_toggle_level()
{
	PORTA_toggle_pin_level(0);
}

/**
 * \brief Get level on PA0
 *
 * Reads the level on a pin
 */
static inline bool PA0_get_level()
{
	return PORTA_get_pin_level(0);
}

/**
 * \brief Set PA1 pull mode
 *
 * Configure pin to pull up, down or disable pull mode, supported pull
 * modes are defined by device used
 *
 * \param[in] pull_mode Pin pull mode
 */
static inline void PA1_set_pull_mode(const enum port_pull_mode pull_mode)
{
	PORTA_set_pin_pull_mode(1, pull_mode);
}

/**
 * \brief Set PA1 data direction
 *
 * Select if the pin data direction is input, output or disabled.
 * If disabled state is not possible, this function throws an assert.
 *
 * \param[in] direction PORT_DIR_IN  = Data direction in
 *                      PORT_DIR_OUT = Data direction out
 *                      PORT_DIR_OFF = Disables the pin
 *                      (low power state)
 */
static inline void PA1_set_dir(const enum port_dir dir)
{
	PORTA_set_pin_dir(1, dir);
}

/**
 * \brief Set PA1 input/sense configuration
 *
 * Enable/disable PA1 digital input buffer and pin change interrupt,
 * select pin interrupt edge/level sensing mode
 *
 * \param[in] isc PORT_ISC_INTDISABLE_gc    = Iterrupt disabled but input buffer enabled
 *                PORT_ISC_BOTHEDGES_gc     = Sense Both Edges
 *                PORT_ISC_RISING_gc        = Sense Rising Edge
 *                PORT_ISC_FALLING_gc       = Sense Falling Edge
 *                PORT_ISC_INPUT_DISABLE_gc = Digital Input Buffer disabled
 *                PORT_ISC_LEVEL_gc         = Sense low Level
 */
static inline void PA1_set_isc(const PORT_ISC_t isc)
{
	PORTA_pin_set_isc(1, isc);
}

/**
 * \brief Set PA1 inverted mode
 *
 * Enable or disable inverted I/O on a pin
 *
 * \param[in] inverted true  = I/O on PA1 is inverted
 *                     false = I/O on PA1 is not inverted
 */
static inline void PA1_set_inverted(const bool inverted)
{
	PORTA_pin_set_inverted(1, inverted);
}

/**
 * \brief Set PA1 level
 *
 * Sets output level on a pin
 *
 * \param[in] level true  = Pin level set to "high" state
 *                  false = Pin level set to "low" state
 */
static inline void PA1_set_level(const bool level)
{
	PORTA_set_pin_level(1, level);
}

/**
 * \brief Toggle output level on PA1
 *
 * Toggle the pin level
 */
static inline void PA1_toggle_level()
{
	PORTA_toggle_pin_level(1);
}

/**
 * \brief Get level on PA1
 *
 * Reads the level on a pin
 */
static inline bool PA1_get_level()
{
	return PORTA_get_pin_level(1);
}







/**
 * \brief Set PA4 pull mode
 *
 * Configure pin to pull up, down or disable pull mode, supported pull
 * modes are defined by device used
 *
 * \param[in] pull_mode Pin pull mode
 */
static inline void PA4_set_pull_mode(const enum port_pull_mode pull_mode)
{
	PORTA_set_pin_pull_mode(4, pull_mode);
}

/**
 * \brief Set PA4 data direction
 *
 * Select if the pin data direction is input, output or disabled.
 * If disabled state is not possible, this function throws an assert.
 *
 * \param[in] direction PORT_DIR_IN  = Data direction in
 *                      PORT_DIR_OUT = Data direction out
 *                      PORT_DIR_OFF = Disables the pin
 *                      (low power state)
 */
static inline void PA4_set_dir(const enum port_dir dir)
{
	PORTA_set_pin_dir(4, dir);
}

/**
 * \brief Set PA4 input/sense configuration
 *
 * Enable/disable PA0 digital input buffer and pin change interrupt,
 * select pin interrupt edge/level sensing mode
 *
 * \param[in] isc PORT_ISC_INTDISABLE_gc    = Iterrupt disabled but input buffer enabled
 *                PORT_ISC_BOTHEDGES_gc     = Sense Both Edges
 *                PORT_ISC_RISING_gc        = Sense Rising Edge
 *                PORT_ISC_FALLING_gc       = Sense Falling Edge
 *                PORT_ISC_INPUT_DISABLE_gc = Digital Input Buffer disabled
 *                PORT_ISC_LEVEL_gc         = Sense low Level
 */
static inline void PA4_set_isc(const PORT_ISC_t isc)
{
	PORTA_pin_set_isc(4, isc);
}
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

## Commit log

2022-04-22 First Commit
    Adds KiCad files
    [NanoFox80.kicad_pcb, NanoFox80.kicad_sch]
2022-04-23 Schematic Updates
    o Specified missing part parameters
    o Added Q101 & Q102, R110, R111, to support battery voltage monitoring
    o Added JP104 and JP105 to support swapping inputs to
    [NanoFox80.kicad_sch]
2022-04-25 Added test points
    Added photos in Docs folder
    Added test points
    [NanoFox80.kicad_sch]
2022-04-26 Updates
    o More parts specified
    o First cut at a PCB
    [NanoFox80.kicad_pcb, NanoFox80.kicad_sch]
2022-04-26 Schematic Update
    o Added ESD diodes
    [NanoFox80.kicad_sch]
2022-04-26 Parts Update
    Changed LED to be a right-angle device
    [NanoFox80.kicad_pcb, NanoFox80.kicad_sch]
2022-04-26 BOM
    o Fixed BOM script
    o Generated preliminary BOM
    [NanoFox80.csv, NanoFox80.kicad_sch]
2022-04-27 Updated Schematic & PCB
    o Corrected varactor circuit
    o Added level translation to USART
    o Added mounting holes to PCB
    [NanoFox80.kicad_pcb, NanoFox80.kicad_sch]
2022-04-27 Rev Update
    Rev 0.3
    [NanoFox80.kicad_sch]
2022-04-28 Schematic Update
    Updated L101 information
    [NanoFox80.kicad_pcb, NanoFox80.kicad_sch]
2022-04-30 PCB Routed
    o First cut at PCB board
    o Gerbers updated
    [NanoFox80-B_Cu.gbl, NanoFox80-B_Mask.gbs, NanoFox80-B_Paste.gbp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]
2022-04-30 PCB Updates
    o Added better silkscreen to X101
    o More stitch vias
    [NanoFox80-B_Cu.gbl, NanoFox80-B_Mask.gbs, NanoFox80-B_Paste.gbp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]
2022-05-01 PCB Updates
    o Added holes for scope probe ground clips
    [NanoFox80-B_Cu.gbl, NanoFox80-B_Mask.gbs, NanoFox80-B_Paste.gbp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]
2022-05-01 PCB Update
    Updated X101 footprint silkscreen
    [NanoFox80-B_Cu.gbl, NanoFox80-B_Mask.gbs, NanoFox80-B_Paste.gbp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]
2022-05-02 Schematic & PCB updates
    o Moved X101 connection to U105
    o Added header to pin 22 of U105
    o Updated schematic and PCB
    o Generated new Gerbers
    [NanoFox80-B_Cu.gbl, NanoFox80-B_Mask.gbs, NanoFox80-B_Paste.gbp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]
2022-05-03 Updated Footprints
    o Corrected U106, U107 and U103 footprints
    o Updated Gerbers
    [NanoFox80-B_Cu.gbl, NanoFox80-B_Mask.gbs, NanoFox80-B_Paste.gbp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]
2022-05-04 Schematic & PCB Updates
    o Fixed pinout of Q101
    o Changed device for U103
    o Corrected PCB for Q101 change
    o Updated PCB Rev
    o Updated BOM
    [NanoFox80-B_Cu.gbl, NanoFox80-B_Mask.gbs, NanoFox80-B_Paste.gbp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]
2022-05-04 Schematic, BOM and PCB Updates
    o Changed parts spec'd for Q101 and Q102
    o Updated footprints
    o Updated PCB
    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
    [NanoFox80-B_Cu.gbl, NanoFox80-B_Mask.gbs, NanoFox80-B_Paste.gbp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]
2022-05-05 Corrected Q102
    Wrong part was specified for Q102.
    Set to BSS138W-7-F and updated BOM
    [NanoFox80.csv, NanoFox80.kicad_sch]
2022-05-05 PCB Update
    o Corrected footprint for U103
    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
    [NanoFox80-B_Cu.gbl, NanoFox80-B_Mask.gbs, NanoFox80-B_Paste.gbp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]
2022-05-05 Moved Gerbers
    o Added a folder to hold all the Gerber files
    [NanoFox80-B_Cu.gbl, NanoFox80-B_Mask.gbs, NanoFox80-B_Paste.gbp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]
2022-06-29 Development for Si5351
    First changes for Si5351 design approach
    [NanoFox80.kicad_sch]
2022-06-30 Development
    o Schematic updates for Si5351 approach
    [NanoFox80.kicad_sch]
2022-06-30 Development
    o Addressed ERC errors
    o Added trimmer capacitor
    o Cosmetic changes to schematic
    [NanoFox80.kicad_sch]
2022-06-30 Development
    o Added WiFi support
    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
    [NanoFox80.kicad_sch, wifi_module.kicad_sch]
2022-07-01 Development
    o Set all footprints to approximate values
    [NanoFox80.kicad_sch, wifi_module.kicad_sch]
2022-07-01 Development
    o Updated version and date information
    [NanoFox80.kicad_sch, wifi_module.kicad_sch]
2022-07-02 Development
    o Changes to footprints in schematic
    [NanoFox80.kicad_sch, wifi_module.kicad_sch]
2022-07-04 Development
    o Footprint edits
    [NanoFox80.kicad_pcb, NanoFox80.kicad_sch]
2022-07-04 Development
    o Tweak X102 footprint on PCB
    [NanoFox80.kicad_pcb]
2022-07-06 Development
    o Fixes to errors in schematic and PCB
    [NanoFox80.kicad_pcb, NanoFox80.kicad_sch, wifi_module.kicad_sch]
2022-07-10 Development
    PCB Updates
    [NanoFox80.kicad_pcb]
2022-07-10 Development
    PCB changes
    [NanoFox80.kicad_pcb]
2022-07-10 Development
    Small PCB tweaks
    [NanoFox80.kicad_pcb]
2022-07-11 Development
    PCB silkscreen change
    [NanoFox80.kicad_pcb]
2022-07-12 PCB Dev
    o Removed copper fill keep out zone beneath X101
    [NanoFox80.kicad_pcb]
2022-07-12 Built Gerbers
    o Uploading built Gerber files
    [NanoFox80-B_Cu.gbl, NanoFox80-B_Mask.gbs, NanoFox80-B_Paste.gbp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]
2022-07-12 PCB Development
    Tweaks to X101 footprint
    [NanoFox80-B_Cu.gbl, NanoFox80-B_Mask.gbs, NanoFox80-B_Paste.gbp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]
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2022-08-07 Development
    o Implemented a DAC setting command for the serial bus.
    o Removed the power-setting command from the serial bus.
2022-08-08 Schematic Update
    o Updated L101 info
    [NanoFox80.kicad_sch]
2022-08-08 Devolopment
    o Added "KEY" serial bus command
    o Bug fixes
    [main.cpp, serialbus.h]
2022-08-09 Debug
    o Corrected a potential infinite loop if the TCXO hardware fails
    [defs.h, main.cpp]
2022-08-09 Development
    o Fixed some LED blink issues
    [defs.h, main.cpp]
2022-08-09 Development
    o Added SLP functionality: SLP 0 disables sleep; SLP 1 re-enables sleep; SLP starts sleep if it isn't enabled
    o Fixes a bug that prevented ADC from working after returning from sleep
    o Ver 0.43
    [defs.h, main.cpp]
2022-08-09 Development
    o The sleep countdown is now reset to 2 minutes every time a serial port command is sent to NanoFox.
    o Ver 0.44
    [defs.h, main.cpp]
2022-08-09 Development
    o Improved sleep current drain. Now down to 336 uA.
    o Ver 0.45
2022-08-09 Schematic Updates
    o Corrected the device symbol for the microcontroller.
    [NanoFox80.kicad_sch]
2022-08-10 Development
    o Fixes several problems that prevented the RTC from incrementing during sleep when using the internal 32 kHz clock.
    [defs.h, main.cpp]
2022-08-10 Development
    o Added full settings prints as confirmation of settings input
    o Ver 0.47
2022-08-11 Development
    o Fix for Morse code timing that could send extra elements after sending the station ID
    o EEPROM variables added for future support of setting foxoring event information
    [defs.h, eeprommanager.cpp, main.cpp]
2022-08-13 Ver 0.51
    o Added code to test the cloning concept. It should successfully set a slave's clock.
    o Added support for enunciating with Morse LED blinks
    o Removed Goertzel algorithm
2022-08-15 Development
    o Fixes an issue preventing time from getting sync'd during cloning process
    o Master will never transmit now
    o 1 short buttonpress should start an event
    o 2 short buttonpresses should stop an event
    o Ver 0.52
    [defs.h, eeprommanager.cpp, main.cpp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]
2022-08-16 Development
    Ver 0.53
    o Fixes to cloning process
    [defs.h, eeprommanager.cpp, main.cpp]
2022-08-16 Development
    Ver 0.54
    o Corrects a problem with Master/Slave sending \n instead of \r.
    o Addresses an issue that might have been corrupting g_foxoring_fox
    [defs.h, eeprommanager.cpp, main.cpp]
2022-08-16 Development
    Prevents a slave from recognizing MAS P<cr> command for one minute following a successful cloning session.
    [main.cpp]
2022-08-17 Ver 0.59
    o Corrects an issue where master would send the start time in the CLK F message
    [defs.h, main.cpp]
2022-08-17 Development
    o Slave LED illuminates continuously while cloning is taking place.
    o Long keypress no longer sends "Master" or "Slave" after a mode transition.
    [main.cpp]
2022-08-21 Ver 0.6
    o Added BAT serial command to display battery voltage and threshold setting.
    o Added a battery threshold setting that sets at what voltage the LED blinks "V" to indicate low battery. By default it is 3.8V.
    o Added a checksum for cloning data, and a master/slave message exchange to implement serial data error detection.
    o Code cleanup and general bug fixes.
    [defs.h, eeprommanager.cpp, main.cpp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]
2022-08-22 Ver 0.61
    o Redesign of EEPROM module. Guard variables added between settings variables.
    o Corrects some problems with event behavior following a sync
    o Corrects some problems with event behavior when going between master and slave mode or changing fox setting.
    [defs.h, eeprommanager.cpp, main.cpp]
2022-08-23 KiCad
    o Schematic updates
    [NanoFox80.kicad_sch]
2022-08-29 Ver 0.62
    o Adds support for RTC calibration using the CLK C nnnnn serial command.
    o Cleans up some EEPROM design elements
    o Minor bug fixes.
    [defs.h, eeprommanager.cpp, main.cpp]
2022-09-01 Ver 0.63
    o Corrects a bug that could prevent the finish time from getting saved when the CLK S serial command was used to set the start time.
    [defs.h, main.cpp]
2022-11-20 Update NanoFox80.kicad_sch
    Rev A proposed changes
    [NanoFox80.kicad_sch]
2022-11-21 +BATT Fix
    Schematic change
    [NanoFox80.kicad_sch, wifi_module.kicad_sch]
2022-11-21 Update NanoFox80.kicad_sch
    Schematic tweaks.
    [NanoFox80.kicad_sch]
2022-11-21 Update NanoFox80.kicad_sch
    More tweaks
    [NanoFox80.kicad_sch]
2022-11-21 Update NanoFox80.kicad_sch
    Schematic tweak - added cap across switch
    [NanoFox80.kicad_sch]
2022-11-22 Schematic Tweaks
    Added missing diode
    [NanoFox80.kicad_sch, wifi_module.kicad_sch]
2022-11-22 Update NanoFox80.kicad_sch
    Schematic tweaks
    [NanoFox80.kicad_sch]
2022-11-22 Schematic
    Upped version number
    [NanoFox80.kicad_sch, wifi_module.kicad_sch]
2023-05-19 Fixed for EEPROM Corruption?
    Made changes to serial port logic to remove most junk characters.
    Set Port C Rx and Tx pins high during sleep.
    Disabled the linkbus, which isn't supported right now
    [defs.h, main.cpp, serialbus.h]
2023-05-30 Development Ver 0.71
    Numerous fixes to serial port operation.
    [defs.h, main.cpp, serialbus.h]
2023-06-02 Serial Port Change
    o When device goes to sleep only two things will re-enable the serial port: 1) cycle power, 2) press button
    o Ver 0.72
2023-06-03 Bug Fix
    Resolves a bug that prevented the foxoring pattern code speed from getting set.
    [defs.h, main.cpp]
2023-06-03 Bug Fix
    Fixes a problem that prevented successful cloning
    [defs.h, main.cpp]
2023-06-04 Bug Fix
    Corrects a problem in which a master would never go to sleep after having completed a cloning session.
    [defs.h, main.cpp]
2023-06-05 Bug Fixes
    Should fix several issues that prevented sleep from occurring.
    [defs.h, main.cpp]
2023-06-05 Sleep Bug Fixes
    More fixes to sleep operation. Ver 0.77
    [defs.h, main.cpp]
2023-06-05 Debugging
    o Corrects a problem during sync in which the cloned frequencies do not get saved to the slave.
    o Corrects a problem in which a single button press will not cause a scheduled event to start immediately.
    [defs.h, main.cpp]
2023-06-06 Bugfix
    Corrects a very tricky issue with Port A Pin 1 when the linkbus is left enabled.
    [defs.h, main.cpp]
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2023-06-29 Minor Bug Fix
    Add <CR> to BAT command response
    [main.cpp]
2023-07-02 Runs Daily
    o Added support for running every day at the same time interval
    o Corrected a bug related to EEPROM storage
    o Corrected a bug related to using the GO 2 command
    [defs.h, eeprommanager.cpp, main.cpp]
2023-07-04 Ver 0.83
    o Removed legacy code for linkbus and Huzzah module
    o Disabled DAC
    o Fixes bugs related to serial port
    o Sleep current is now 250uA
    [defs.h, main.cpp]
2023-07-12 Ver 0.84
    o Changed multi-day event setting CLK D to set the number of days to run, instead of running forever
    o Minor bug fixes
    [defs.h, eeprommanager.cpp, main.cpp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]
2023-07-19 Ver 0.86
    o Synchronize clocks to seconds transition when syncing clocks to improve precision of synchronization
    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
    [defs.h, main.cpp]
2023-07-19 Ver 0.87
    o Corrects a bug that could cause the sleep time to be too short after an event is suspended.
    [defs.h, main.cpp]
2023-07-20 Ver 0.88
    o Fixes a situation that could result in the LED being left on continuously for an indefinite period of time.
    [defs.h]
2023-07-22 Ver 0.89
    o Corrects a bug that could result in a synced device not starting a programmed event.
    [defs.h, main.cpp]
2023-07-22 Ver 0.90
    o Corrects an issue that could cause some sync messages to be ignored due to unintended data in the message data fields.
    [defs.h, main.cpp]
2023-07-28 Ver 0.91
    o Updated toolchain. New zip file included with extension "update"
    o Fixes some sleep issues
    o Fixes some minor syntax errors
    [defs.h, main.cpp]
2023-07-29 Ver 0.92
    o Added VER serial test command to retrieve SW version
    o Fixes some EEPROM variable size issues that might result in data corruption
    o Fixes minor bug issues
    [defs.h, eeprommanager.cpp, main.cpp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]
2023-07-29 Ver 0.93
    Corrects a problem that could result in the wrong pattern code speed being sent.
    [defs.h, main.cpp]
2023-07-30 Ver 0.94
    o Bug fixes related to sleep and event startup
    [defs.h, main.cpp]
2023-07-30 Ver 0.95
    Corrects a problem that prevented entering Master Mode if an event is running.
    [defs.h, main.cpp]
2023-07-30 Ver 0.96
    Corrects a problem where the LED could start blinking garbage after returning from Master setting.
    [defs.h, main.cpp]
2023-07-31 Ver 0.97
    o Corrects several bugs related to pushbutton operation
    o Corrects a bug that could cause Morse characters to be sent by the LED after returning from sleep
    [defs.h, main.cpp]
2023-07-31 Ver 0.98
    o Corrects a bug that can cause the LED to blink Morse patterns when it should not.
    [defs.h, main.cpp]
2023-09-12 Debug
    o Fixes an issue with the "Days" feature that could cause a 1-day event to repeat.
    o Adds an I2C error counter and a DBG command to read it
    [main.cpp, serialbus.h]
2023-10-08 I2C Error Count
    Added a debug timeout counter for debugging
    [defs.h, eeprommanager.cpp, main.cpp]
2023-10-09 Bugfix & Debug
    o Adds I2C debug support
    o Fixes issue causing Master not to blink LED
    [eeprommanager.cpp, main.cpp]
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
